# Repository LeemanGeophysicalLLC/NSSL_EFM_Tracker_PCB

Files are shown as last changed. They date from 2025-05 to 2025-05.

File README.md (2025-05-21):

# NSSL EFM Tracker PCB

The tracker provides GPS location data to instrument operators via a satellite  
connection. It is designed to enable easy location of the instrument package during  
and after flight, supporting both flight termination decisions and efficient recovery  
of the full payload. The tracker uses a progressive rate strategy to optimize battery  
life, providing high-rate position updates during the most dynamic and critical phases  
of the flight.

See the [main instrument repo](https://github.com/LeemanGeophysicalLLC/NSSL_EFM_Instrument)
for documentation and the rest of the instrument.

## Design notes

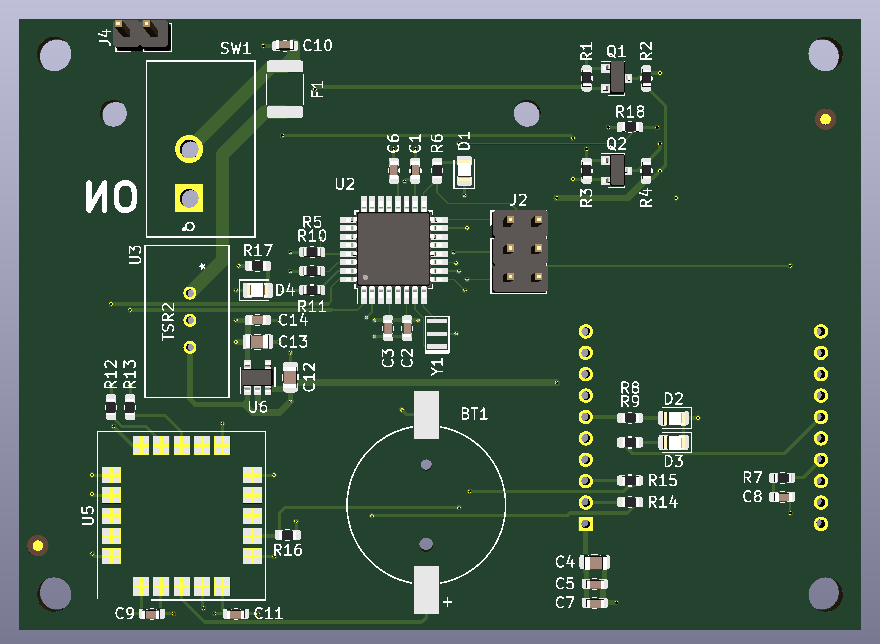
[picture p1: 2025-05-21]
Renders/pcb_front.png

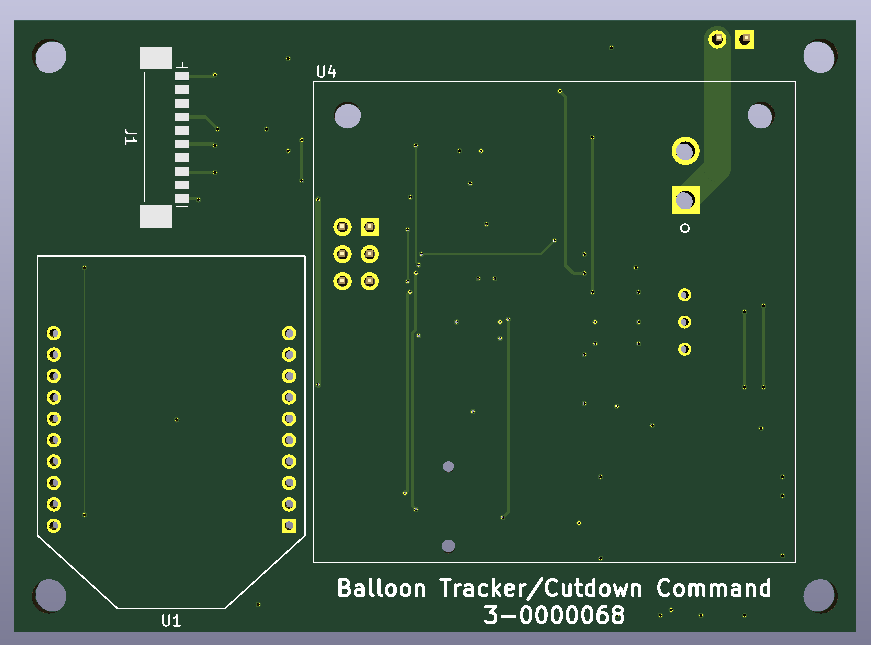
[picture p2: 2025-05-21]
Renders/pcb_back.png

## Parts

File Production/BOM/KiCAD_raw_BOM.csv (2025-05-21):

Reference | Value | Footprint | Datasheet | Internal Part Number | Populated | PValue
J1 | RockBlock9603 | lib_fp:picoblade | ~ | 1-0000790 | 1
U5 | ublox_SAM-M8Q | RF_GPS:ublox_SAM-M8Q | https://www.u-blox.com/sites/default/files/SAM-M8Q_DataSheet_%28UBX-16012619%29.pdf | 1-0000446 | 1
BT1 | CR1220 | lib_fp:S8411-45R | ~ | 1-0000246 | 1
C11 | 1-0000007 | capacitors_0603:1-0000007 | ~ | 1-0000007 | 1 | 0.1uF
C9 | 1-0000007 | capacitors_0603:1-0000007 | ~ | 1-0000007 | 1 | 0.1uF
U1 | XBee | lib_fp:XBee |  | 1-0000785 | 1
U3 | TSR2 | lib_fp:TSR 2-2450 |  | 1-0000748 | 1
J4 | Battery | Connector_PinHeader_2.54mm:PinHeader_1x02_P2.54mm_Vertical | ~ | 0-0000000 | 0
SW1 | SW_SPST | lib_fp:SW_GF-123-0054 | ~ | 1-0000786 | 1
J3 | Switch | Connector_PinHeader_2.54mm:PinHeader_1x02_P2.54mm_Vertical | ~ | 0-0000000 | 0
U6 | MIC5219-3.3YM5 | Package_TO_SOT_SMD:SOT-23-5 | http://ww1.microchip.com/downloads/en/DeviceDoc/MIC5219-500mA-Peak-Output-LDO-Regulator-DS20006021A.pdf | 1-0000658 | 1
F1 | Polyfuse | Fuse:Fuse_1812_4532Metric | ~ | 1-0000002 | 1
C10 | 1-0000007 | capacitors_0603:1-0000007 | ~ | 1-0000007 | 1 | 0.1uF
C14 | 1-0000007 | capacitors_0603:1-0000007 | ~ | 1-0000007 | 1 | 0.1uF
J2 | ICSP | Connector_PinHeader_2.54mm:PinHeader_2x03_P2.54mm_Vertical | ~ | 0-0000000 | 0
C5 | 1-0000018 | capacitors_0603:1-0000018 | ~ | 1-0000018 | 1 | 1uF
C7 | 1-0000007 | capacitors_0603:1-0000007 | ~ | 1-0000007 | 1 | 0.1uF
U2 | ATmega328P-AU | Package_QFP:TQFP-32_7x7mm_P0.8mm |  | 1-0000566 | 1
C6 | 1-0000007 | capacitors_0603:1-0000007 | ~ | 1-0000007 | 1 | 0.1uF
Y1 | 16MHz | lib_fp:Resonator | ~ | 1-0000569 | 1
R5 | 1-0000010 | resistors_0603:1-0000010 | ~ | 1-0000010 | 1 | 10k
C1 | 1-0000007 | capacitors_0603:1-0000007 | ~ | 1-0000007 | 1 | 0.1uF
C2 | 1-0000007 | capacitors_0603:1-0000007 | ~ | 1-0000007 | 1 | 0.1uF
C3 | 1-0000007 | capacitors_0603:1-0000007 | ~ | 1-0000007 | 1 | 0.1uF
R10 | 1-0000006 | resistors_0603:1-0000006 | ~ | 1-0000006 | 1 | 0R0
R11 | 1-0000006 | resistors_0603:1-0000006 | ~ | 1-0000006 | 1 | 0R0
R12 | 1-0000006 | resistors_0603:1-0000006 | ~ | 1-0000006 | 1 | 0R0
R13 | 1-0000006 | resistors_0603:1-0000006 | ~ | 1-0000006 | 1 | 0R0
R14 | 1-0000006 | resistors_0603:1-0000006 | ~ | 1-0000006 | 1 | 0R0
R15 | 1-0000006 | resistors_0603:1-0000006 | ~ | 1-0000006 | 1 | 0R0
R8 | 1-0000008 | resistors_0603:1-0000008 | ~ | 1-0000008 | 1 | 150
D2 | Blue | LED_SMD:LED_0805_2012Metric | ~ | 1-0000599 | 1
R9 | 1-0000008 | resistors_0603:1-0000008 | ~ | 1-0000008 | 1 | 150
D3 | Yellow | LED_SMD:LED_0805_2012Metric | ~ | 1-0000601 | 1
R7 | 1-0000006 | resistors_0603:1-0000006 | ~ | 1-0000006 | 0 | NP
C8 | 1-0000007 | capacitors_0603:1-0000007 | ~ | 1-0000007 | 0 | 0.1uF
R16 | 1-0000010 | resistors_0603:1-0000010 | ~ | 1-0000010 | 0 | NP
R18 | 1-0000010 | resistors_0603:1-0000010 | ~ | 1-0000010 | 0 | NP
R17 | 1-0000008 | resistors_0603:1-0000008 | ~ | 1-0000008 | 1 | 150
D4 | Green | LED_SMD:LED_0805_2012Metric | ~ | 1-0000598 | 1
R6 | 1-0000008 | resistors_0603:1-0000008 | ~ | 1-0000008 | 1 | 150
D1 | Blue | LED_SMD:LED_0805_2012Metric | ~ | 1-0000599 | 1
Q1 | BSS138 | Package_TO_SOT_SMD:SOT-23 | https://www.onsemi.com/pub/Collateral/BSS138-D.PDF | 1-0000340 | 1
R1 | 1-0000013 | resistors_0603:1-0000013 | ~ | 1-0000013 | 1 | 1k
R2 | 1-0000013 | resistors_0603:1-0000013 | ~ | 1-0000013 | 1 | 1k
Q2 | BSS138 | Package_TO_SOT_SMD:SOT-23 | https://www.onsemi.com/pub/Collateral/BSS138-D.PDF | 1-0000340 | 1
R3 | 1-0000013 | resistors_0603:1-0000013 | ~ | 1-0000013 | 1 | 1k
R4 | 1-0000013 | resistors_0603:1-0000013 | ~ | 1-0000013 | 1 | 1k
U4 | RockBlockMechanical | lib_fp:RockBlock_Mechanical |  | 1-0000789 | 1
FID1 | Fiducial | Fiducial:Fiducial_1mm_Mask2mm | ~ | 0-0000000 | 0
FID2 | Fiducial | Fiducial:Fiducial_1mm_Mask2mm | ~ | 0-0000000 | 0
H1 | MountingHole | MountingHole:MountingHole_3.2mm_M3_DIN965 | ~ | 0-0000000 | 0
H2 | MountingHole | MountingHole:MountingHole_3.2mm_M3_DIN965 | ~ | 0-0000000 | 0
H3 | MountingHole | MountingHole:MountingHole_3.2mm_M3_DIN965 | ~ | 0-0000000 | 0
H4 | MountingHole | MountingHole:MountingHole_3.2mm_M3_DIN965 | ~ | 0-0000000 | 0
C13 | 1-0000075 | capacitors_0805:1-0000075 | ~ | 1-0000075 | 1 | 10uF
C12 | 1-0000075 | capacitors_0805:1-0000075 | ~ | 1-0000075 | 1 | 10uF
C4 | 1-0000075 | capacitors_0805:1-0000075 | ~ | 1-0000075 | 1 | 10uF
PCB1 | barepcb | lib_fp:BarePCB |  | 3-0000068 | 1

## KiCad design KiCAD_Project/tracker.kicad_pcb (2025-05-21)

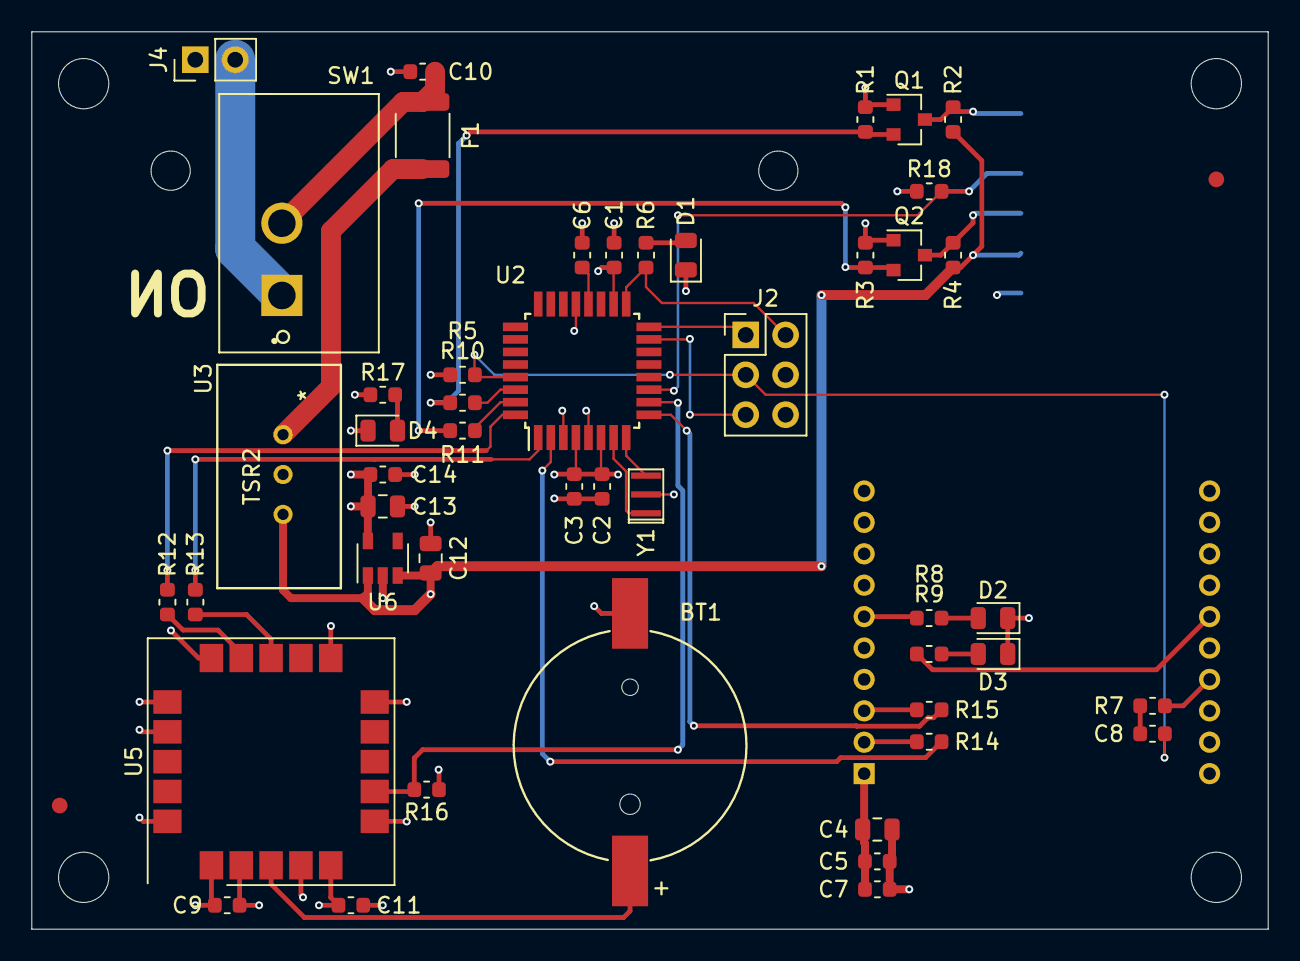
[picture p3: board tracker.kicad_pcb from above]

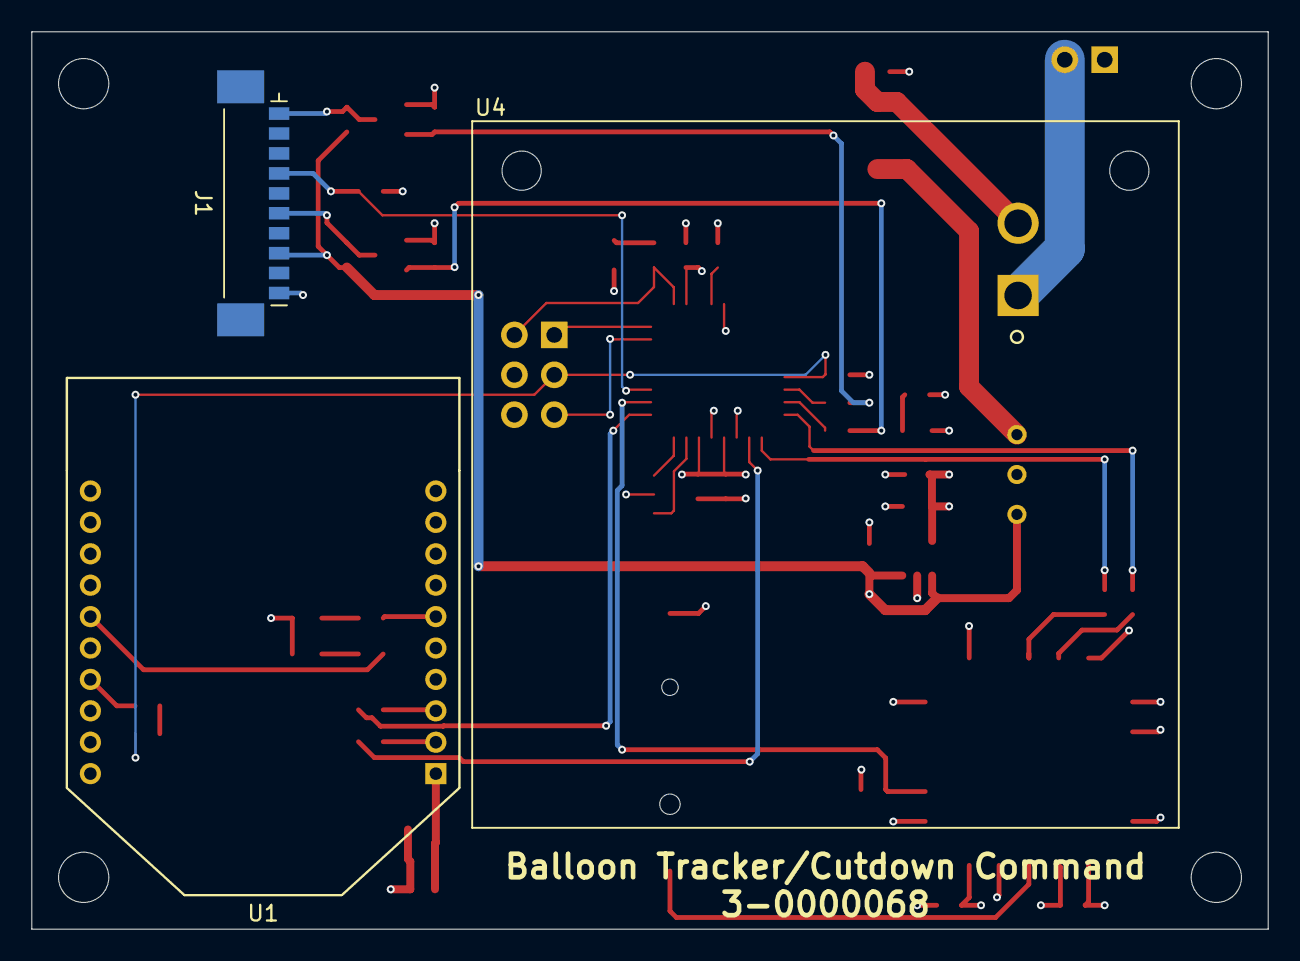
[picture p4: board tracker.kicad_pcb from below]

Board: 4 copper layers, 78.7 x 57.2 mm, 58 parts (3 on the bottom side), 38 nets.

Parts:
BT1: CR1220; S8411-45R
C1, C2, C3, C6, C7, C8, C9, C10, C11, C14: 1-0000007
C4, C12, C13: 1-0000075
C5: 1-0000018
D1, D2: Blue; LED_0805_2012Metric
D3: Yellow; LED_0805_2012Metric
D4: Green; LED_0805_2012Metric
F1: Polyfuse; Fuse_1812_4532Metric
FID1, FID2: Fiducial; Fiducial_1mm_Mask2mm
H1, H2, H3, H4: MountingHole; MountingHole_3.2mm_M3_DIN965
J1: RockBlock9603; picoblade
J2: ICSP; PinHeader_2x03_P2.54mm_Vertical
J4: Battery; PinHeader_1x02_P2.54mm_Vertical
PCB1: barepcb; BarePCB
Q1, Q2: BSS138; SOT-23
R1, R2, R3, R4: 1-0000013
R5, R16, R18: 1-0000010
R6, R8, R9, R17: 1-0000008
R7, R10, R11, R12, R13, R14, R15: 1-0000006
SW1: SW_SPST; SW_GF-123-0054
U1: XBee
U2: ATmega328P-AU; TQFP-32_7x7mm_P0.8mm
U3: TSR2; TSR 2-2450
U4: RockBlockMechanical; RockBlock_Mechanical
U5: ublox_SAM-M8Q
U6: MIC5219-3.3YM5; SOT-23-5
Y1: 16MHz; Resonator

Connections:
+3V3: C1.1, C2.1, C3.1, C4.1, C5.1, C7.1, C9.1, C11.1, C13.1, C14.1, J2.6, Q1.1, Q2.1, R1.1, R3.1, R5.1, R16.1, R17.1, R18.1, U1.1, U2.4, U2.6, U2.18, U5.2, U5.17, U6.5
GPS_PPS: R16.2, U2.10, U5.7
GPS_RX: R12.1, U5.14
GPS_TX: R13.1, U5.13
MISO: J2.1, U2.16
MOSI: J2.5, U2.15
unnamed: BT1.1, U5.3
unnamed: C6.1, U2.20
unnamed: C8.2, R7.1
unnamed: C10.1, F1.2, SW1.2
unnamed: D1.2, R6.2
unnamed: D2.2, R8.2
unnamed: D3.2, R9.2
unnamed: D4.2, R17.2
unnamed: F1.1, U3.1
unnamed: J4.2, SW1.1
unnamed: R7.2, U1.17
unnamed: R8.1, U1.6
unnamed: R9.1, U1.15
unnamed: R10.2, U2.30
unnamed: R11.2, U2.31
unnamed: R12.2, U2.32
unnamed: R13.2, U2.1
unnamed: R14.2, U2.2
unnamed: R15.2, U2.9
unnamed: U2.7, Y1.1
unnamed: U2.8, Y1.3
RB_5V: C12.1, J1.8, R2.1, R4.1, U3.3, U6.1, U6.3
RB_GND: BT1.2, C1.2, C2.2, C3.2, C4.2, C5.2, C6.2, C7.2, C9.2, C10.2, C11.2, C12.2, C13.2, C14.2, D1.1, D2.1, D3.1, D4.1, J1.10, J2.4, J4.1, U1.10, U2.3, U2.5, U2.21, U3.2, U5.1, U5.4, U5.5, U5.6, U5.10, U5.11, U5.15, U5.16, U5.20, U6.2, Y1.2
RB_NetAv: J1.4, R18.2, U2.11
RB_RXI: J1.6, Q2.3, R4.2
RB_RXI_3V3: Q2.2, R3.2, R11.1
RB_TXO: J1.1, Q1.3, R2.2
RB_TXO_3V3: Q1.2, R1.2, R10.1
RESET: C8.1, J2.3, R5.2, U2.29
SCK: J2.2, R6.1, U2.17
XBee_from_Uc: R15.1, U1.3
XBee_to_Uc: R14.1, U1.2

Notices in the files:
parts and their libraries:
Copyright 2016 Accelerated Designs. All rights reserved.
